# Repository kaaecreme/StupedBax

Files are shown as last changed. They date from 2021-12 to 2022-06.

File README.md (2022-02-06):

# StupedBax
<br />

<!-- ABOUT THE PROJECT --> 

### Built With
* Atmega328 (Programmed with Arduino Nano)
* 1x SG90 Servo
* 1x MG90S Servo (with greather torque than SG90 - aprox 2.2kg/cm at 6V)
* 1x Switch button
* 1x IRF9Z34 MOSFET P-channel
* 1x 1N5819 Diode
* 2x 10k resistor
* 1x 220 resistor
* 1x 6V power supply
* Jump wires

## Schematics
### Breadboard
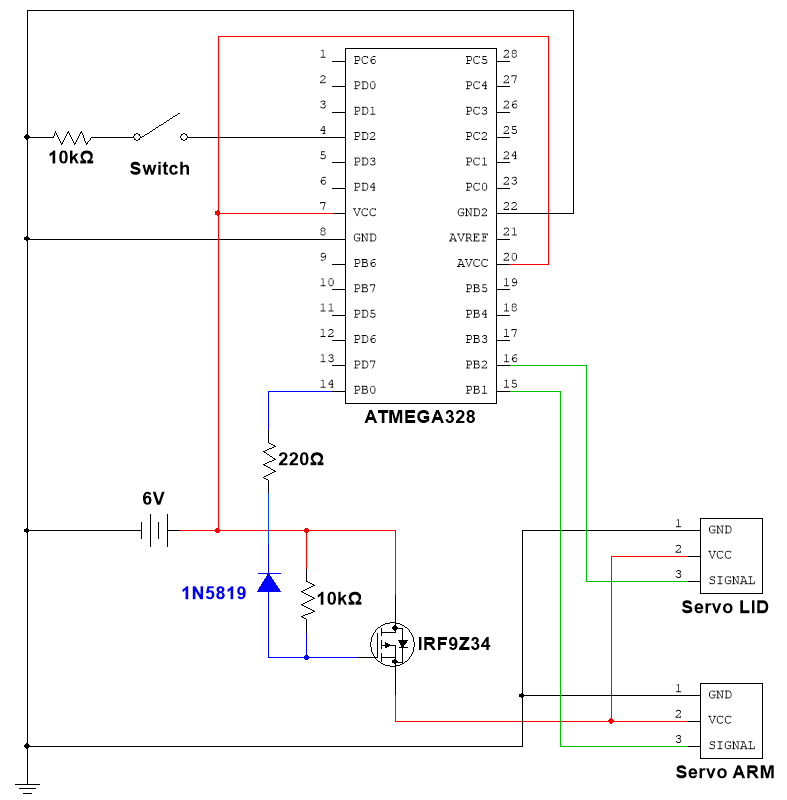
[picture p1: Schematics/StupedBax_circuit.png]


### Upload from Arduino Nano to Mega328
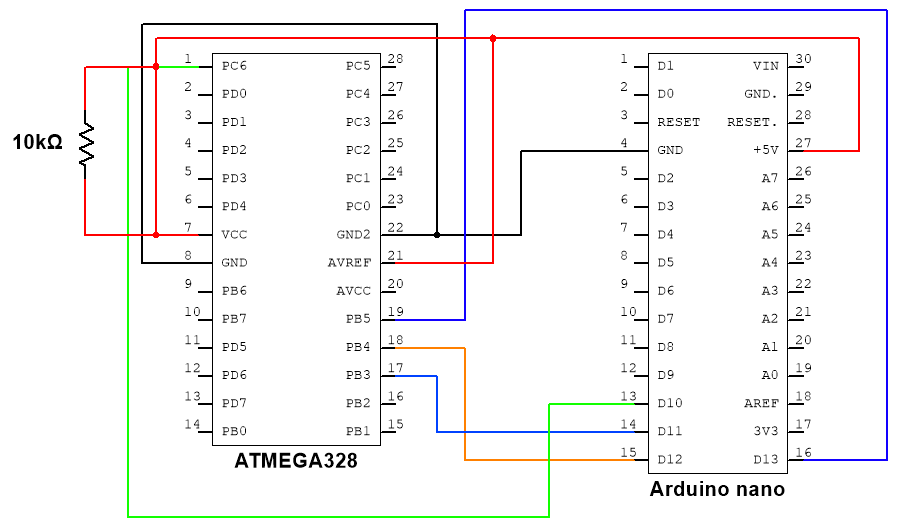
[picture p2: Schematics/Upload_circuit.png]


<!-- USAGE EXAMPLES -->
## Usage

Flick button. Done.
<p align="right">(<a href="#top">back to top</a>)</p>

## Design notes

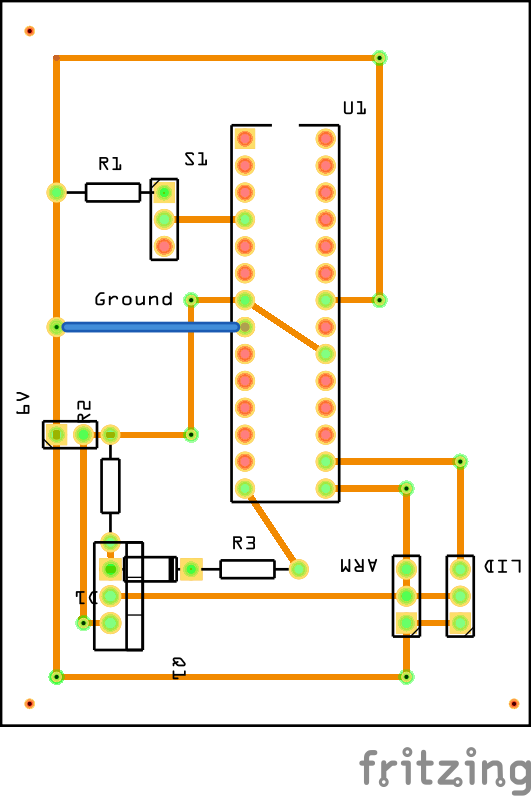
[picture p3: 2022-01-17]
Schematics/StupedBaxPCB_pcb.png

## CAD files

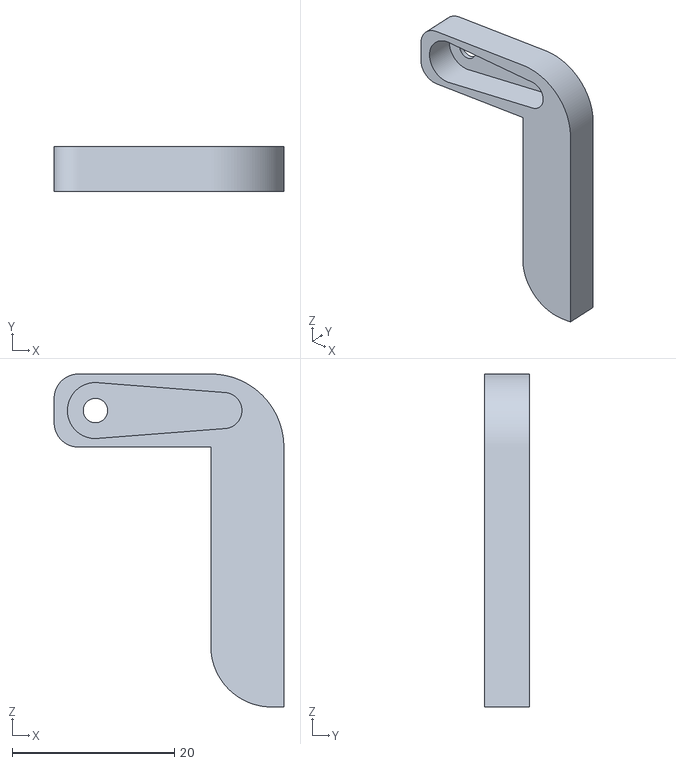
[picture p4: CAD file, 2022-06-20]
Models/SwitchArm.stl
28.3 x 5.50 x 41.0

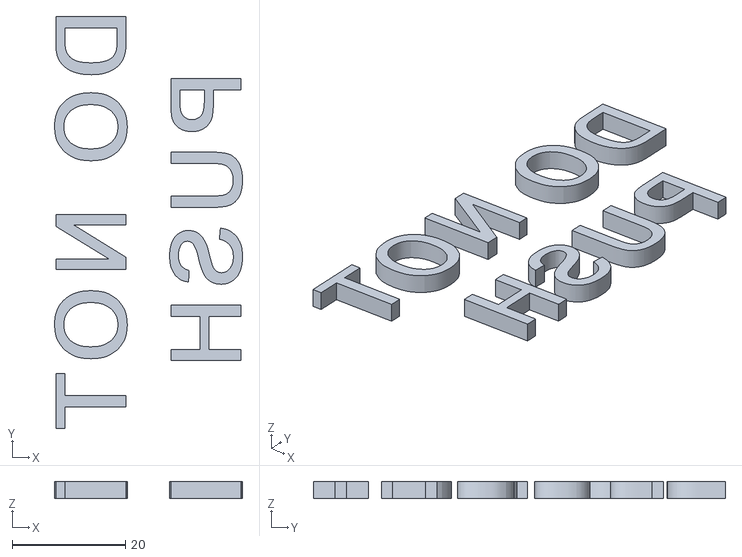
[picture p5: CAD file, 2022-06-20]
Models/Text.stl
33.1 x 72.7 x 3.00

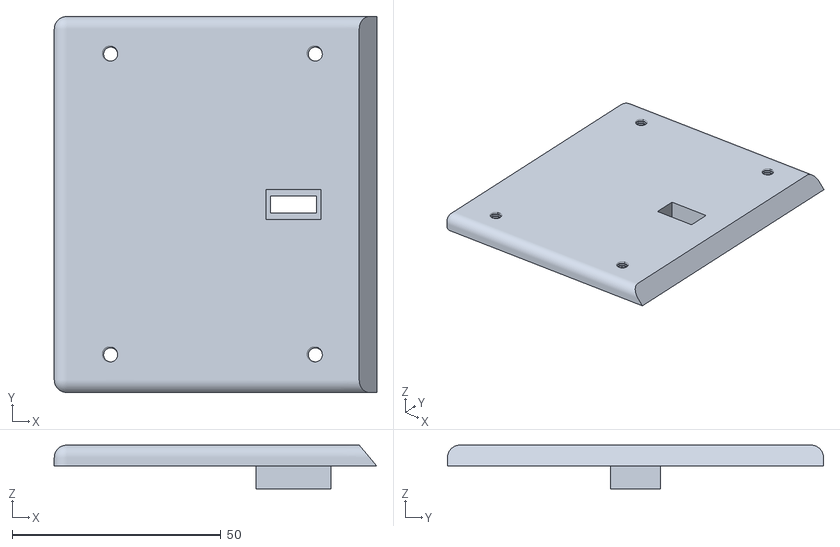
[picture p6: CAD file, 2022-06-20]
Models/SwitchLid.stl
77.2 x 90.0 x 10.5

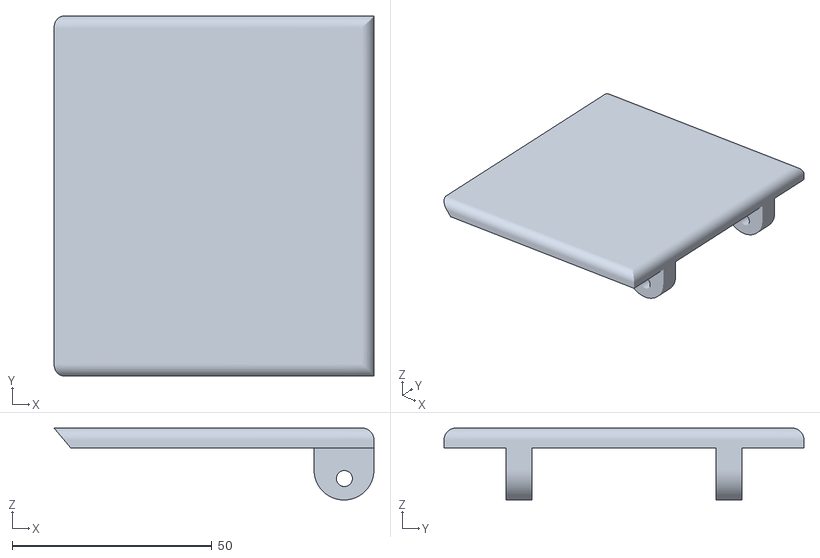
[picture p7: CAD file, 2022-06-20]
Models/OpeningLid.stl
80.0 x 90.0 x 18.0

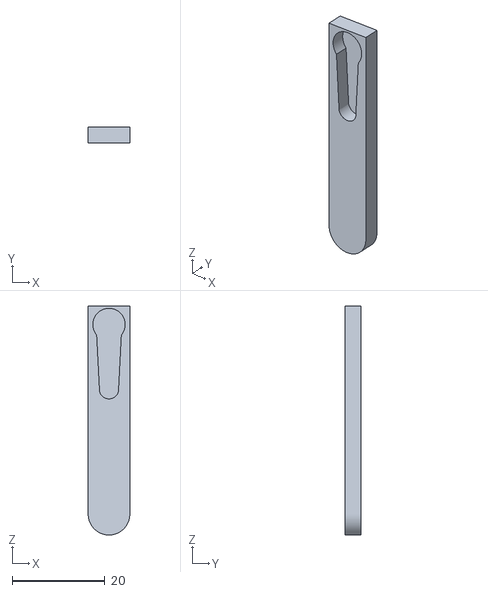
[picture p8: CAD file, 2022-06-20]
Models/LidArm.stl
9.00 x 3.50 x 49.5

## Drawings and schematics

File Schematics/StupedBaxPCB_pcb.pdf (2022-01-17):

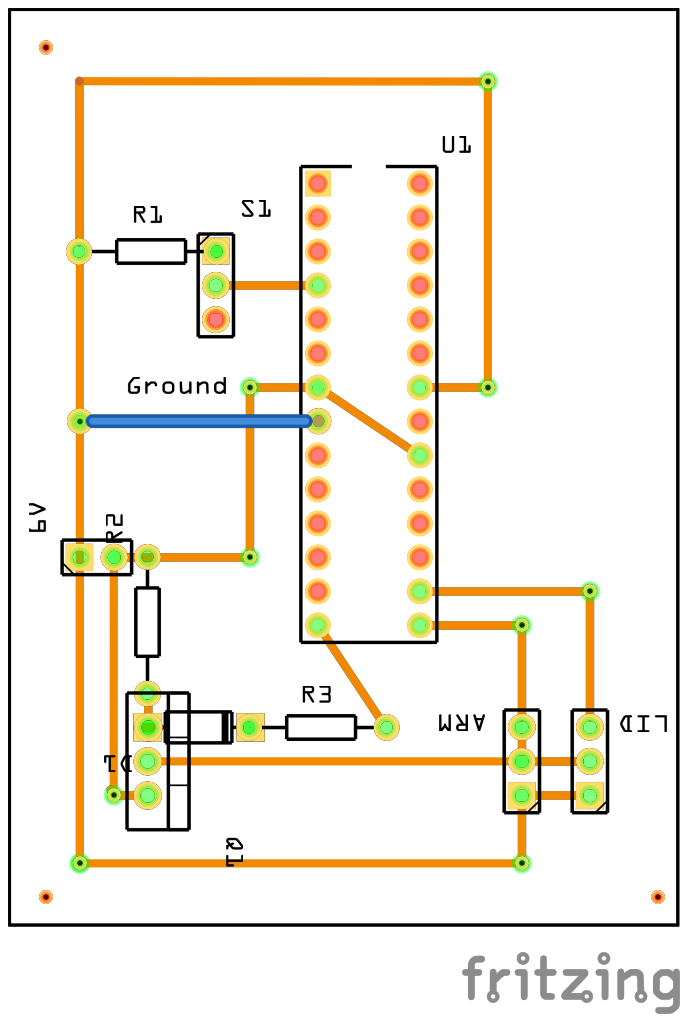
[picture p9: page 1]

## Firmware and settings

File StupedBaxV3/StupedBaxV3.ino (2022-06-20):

#include <avr/sleep.h>
#include <Servo.h>

volatile const int wakePin = 2; // pin used for waking up
volatile const int LEDPin = 7;
volatile const int armPin = 9;
volatile const int lidPin = 10;
volatile const int mosfetPin = 8;

volatile int isActive;
volatile int pos = 0;
volatile int lidPos = 110;
volatile int LA = 0;
volatile int AA = 0;

//Arm
// Hit = 145
// Close = 0

//Lid
// Open = 0 / 10 (fully) (30 - exact)
// Closed = approx 110
 
//Create servo
Servo armServo;
Servo lidServo;

///////////////////////////////////////////////////////////////////////////////////
void setup() {

  ///// Settings //////
  LA = 0; // Lid offset
  AA = -13; // Arm offset
  
  pinMode(wakePin, INPUT_PULLUP); 
  pinMode(mosfetPin, OUTPUT);

  /////////////////////////////////
  digitalWrite(mosfetPin, LOW);
  armServo.attach(armPin);
  armServo.write(0);

  lidServo.attach(lidPin);
  lidServo.write(lidPos);
  delay(1000);
  digitalWrite(mosfetPin, HIGH);
  /////////////////////////////////

  // Check init values to ensure correct sleep
  if (digitalRead(wakePin) == LOW) { // If switch is turned on enable sleep interrupt
    isActive = 1;
    attachInterrupt(0, setSleep, HIGH);
  } else {
    isActive = 0;
    sleepNow(); // If switch is off go to sleep
  }

}

///////////////////////////////////////////////////////////////////////////////////
void loop() {
  if ((digitalRead(wakePin) == LOW) && (isActive == 1)) { 
    digitalWrite(mosfetPin, LOW);
 
    switch (random(1, 6+1)) {

      case 1:
        run1();
        break;

      case 2:
        run2();
        break;

     case 3:
        run3();
        break;

     case 4:
        run4();
        break;
        
     case 5:
        run5();
        break;
        
     case 6:
        run6();
        break;

      default:
        break;

    }

    delay(500);
    sleepNow();

  } else {
    sleepNow();
  }

}

///////////////////////////////////////////////////////////////////////////////////

void sleepNow()
{ 
  digitalWrite(mosfetPin, HIGH);

  sleep_enable();
  detachInterrupt(0); // Remove the sleep interrupt
  attachInterrupt(0, wakeUpNow, LOW); // Add wakeUp interrupt
  set_sleep_mode(SLEEP_MODE_PWR_DOWN);
  sleep_cpu();//activating sleep mode   

}

///////////////////////////////////////////////////////////////////////////////////
void setSleep() { // Here goes the interrupt when going to sleep
  isActive = 0;
}


void wakeUpNow() // Here goes the interrupt when getting awake
{
  sleep_disable(); //Disable sleep mode.
  detachInterrupt(0); //Remove interrupt from pin2
  attachInterrupt(0, setSleep, HIGH); // Enable sleep interrupt
  isActive = 1;
}



///////////////////////////////////////////////////////////////////////////////////
// Tease
void run1() {
  openLid(30, 30);
  forward(134, 30);
  hold(2000);
  back(50, 30);
  forward(155, 0);

  while (isActive) {}
  backEnd(0, 20);
  closeLid(110, 20);
}
 
//Quick
void run2() {
  openLid(30, 10);
  forward(155, 1);

  while (isActive) {}
  backEnd(0, 10); 
  closeLid(110, 10);
}

//Really quick
void run3() { 
  openLid(30, 5);
  forward(155, 0);

  while (isActive) {}
  backEnd(0, 10);  
  closeLid(110, 1);
}

//Really really quick
void run4() {  
  forward(155, 0);

  while (isActive) {}
  backEnd(0, 0);   
}

//Funny open/close
void run5() { 
  openLid(55, 5);
  closeLid(110,5);
  openLid(55, 5);
  closeLid(110,5);
  openLid(55, 5);
  closeLid(110,5); 
  hold(3000);

  openLid(30, 5);
  forward(155, 1);
  
  while (isActive) {}
  backEnd(0, 10);  
  closeLid(110, 10);
}

//Open lid, look
void run6() { 
  openLid(80, 2);
  hold(3000);
  closeLid(110,2);
  hold(2000);
  forward(155, 0);

  while (isActive) {}
  backEnd(0, 0);   
}


void openLid(int newPos, int speed) {

  for (unsigned int i = lidPos; i > newPos && isActive == 1; i -= 2) {
    lidPos -= 2;
    lidServo.write(i+LA);
    delay(speed);
  }

}

void closeLid(int newPos, int speed) {
  for (unsigned int i = lidPos; i < newPos; i += 2) {
    lidPos += 2;
    lidServo.write(i+LA);
    delay(speed);
  }
}


void forward(int newPos, int speed) {

  for (unsigned int i = pos; i < newPos && isActive == 1; i += 2) {
    pos += 2;
    armServo.write(i+AA);
    delay(speed);
  }
}

void back(int newPos, int delayTime) {
  for (unsigned int i = pos; i > newPos && isActive == 1; i -= 2) {
    pos -= 2;
    armServo.write(pos+AA);
    delay(delayTime);
  }

}

void backEnd(int newPos, int delayTime) {
  for (unsigned int i = pos; i > newPos; i -= 2) {
    pos -= 2;
    armServo.write(pos+AA);
    delay(delayTime);
  }
  pos = newPos;
}

void hold(int ms) {
  for (unsigned int i = 0; i <= 100 && isActive == 1; i += 1) {
    delay(ms / 100);
  }
}

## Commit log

2021-12-20 Test with 2 servos
    Didnt work lol
2021-12-20 Work with 2 servos
    Working!
2021-12-21 Changed from n-channel mosfet to p-channel
2021-12-23 Upload of schematics
2021-12-25 Upload from nano to mega328 schematics
    Also change of color in stupedbax schematics
2021-12-28 Change of pins (Now works with both servos)
    Also correct coloring of jump wires in comparison to circuit schematics
    [StupedBaxV3.ino]
2021-12-29 Change of circuit
    Added resistor to digital output pin PB0 to prevent current spike to the arduino pin (When switching the digital output pin)
2022-01-11 Oprettelse af PCB
    [StupedBaxPCB.fzz]
2022-01-17 PCB som PDF
    [StupedBaxPCB.fzz]
2022-01-18 Tilføjet diode og ny modstand ved MOSFET signal
2022-02-06 Ændring af værdier ift. servolid
    Nu er 0 åbent, og 110 ca er lukket
2022-04-08 Redo of code
    Now with sensor!!!
2022-04-30 Revert "Redo of code"
    This reverts commit 7698511ea57d03b25205a15f6ad8299f6a514ed4.
    [StupedBaxV3.ino]
2022-05-01 Added more modes
    Renamed variables for better understanding.
    Added adjusting of offset for both arm and lid servo
2022-06-20 Upload of 3D models and finished code
    [LidArm.stl, OpeningLid.stl, SwitchArm.stl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]
